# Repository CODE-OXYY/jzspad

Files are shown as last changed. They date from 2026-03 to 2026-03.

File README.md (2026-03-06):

# Custom Multi-Purpose Macropad (jzspad)

A multi-purpose macropad featuring 9 customizable LED-backlit keys, 1 rotary encoder, and an OLED display. Powered by the Seeed Studio XIAO RP2040, The keys change depending on the program, but for now they are copy, paste, undo, mute, cam off, close tab, play / pause, screenshot, and most important- show Desktop :)

## 🛠️ Hardware & PCB Design
## SCHEMATIC

The schematic was designed using KiCad all peripherals (OLED, LEDs, Encoder, Matrix) fit perfectly within the 11 available GPIO pins.

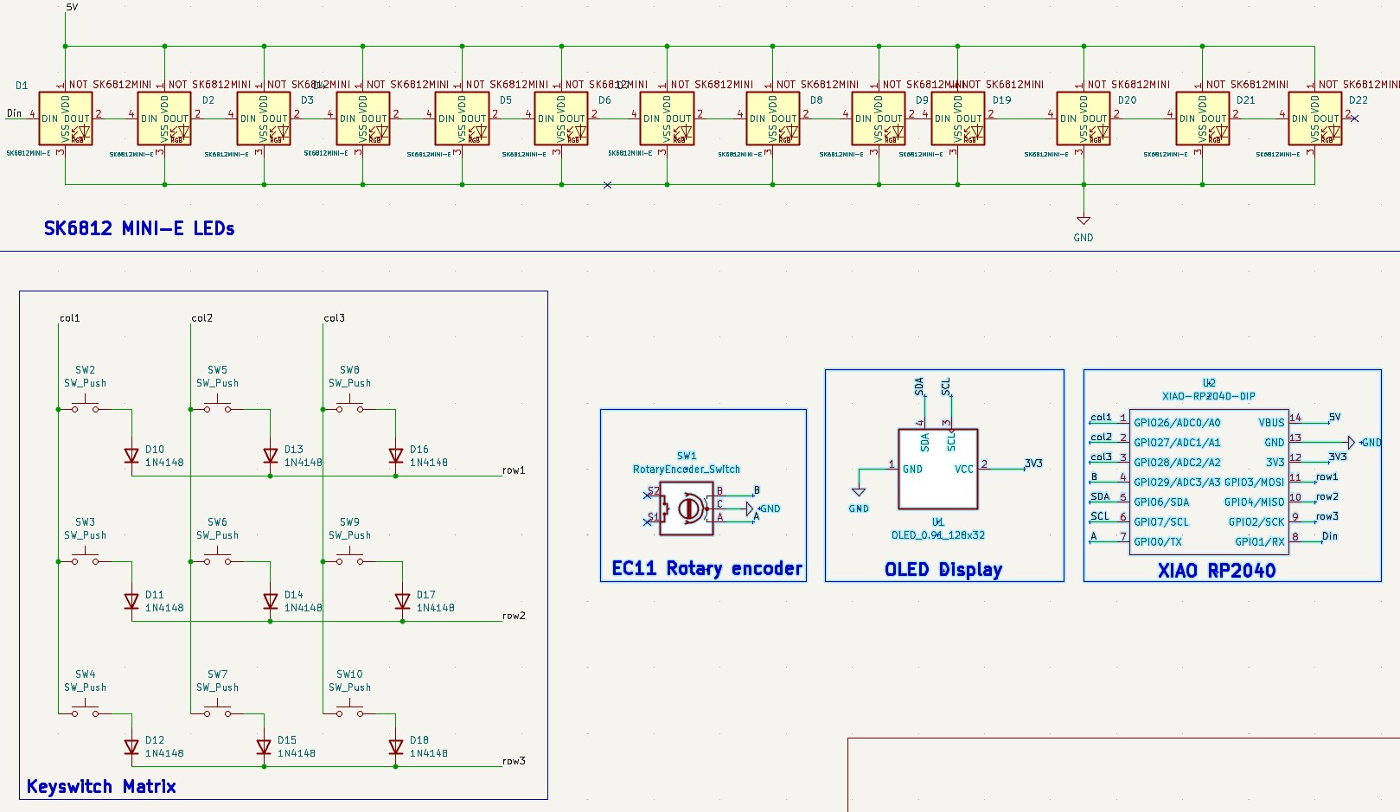
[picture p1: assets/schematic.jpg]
schematic


## PCB LAYOUT

Designed at a precise 98mm x 75mm, staying  Under the 100x100mm threshold.

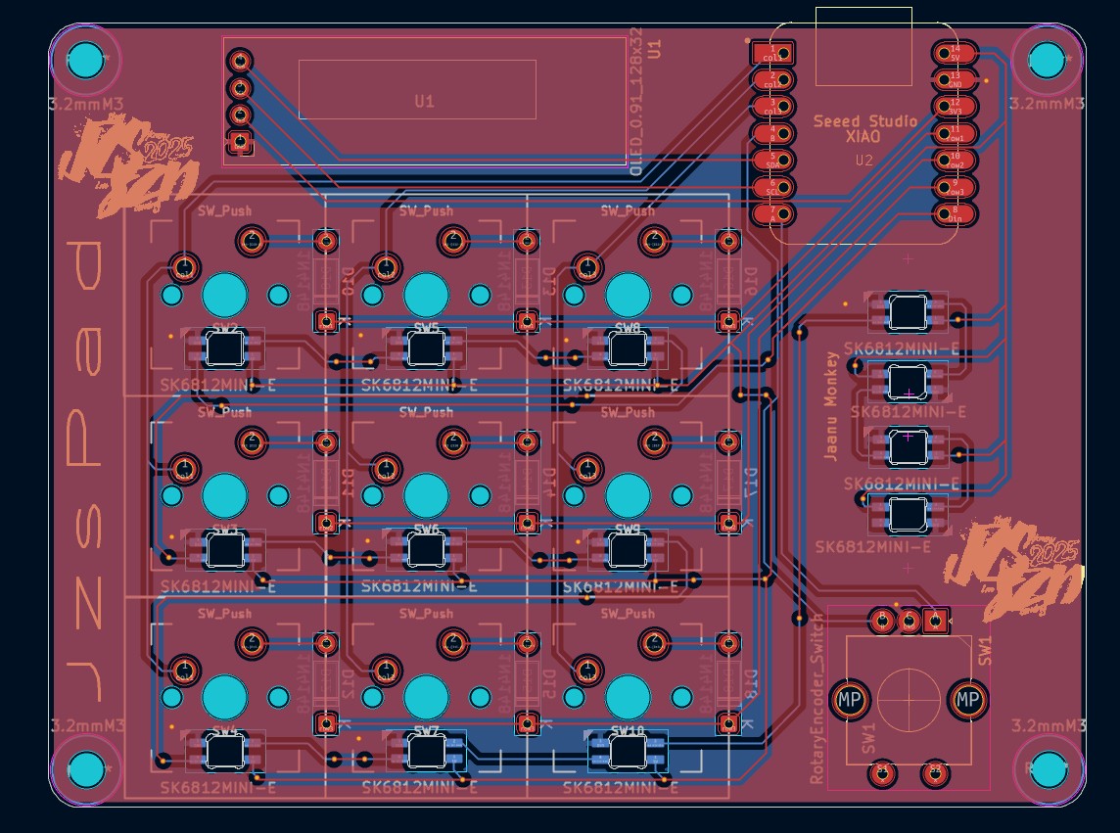
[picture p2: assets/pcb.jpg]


## PCB 3D
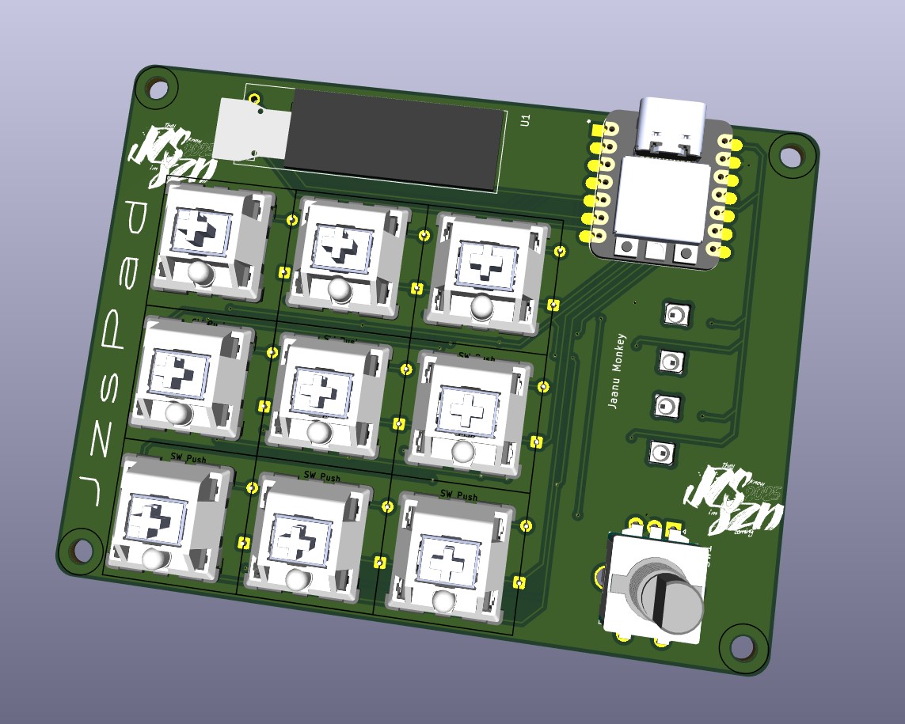
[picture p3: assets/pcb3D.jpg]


## 📦 Mechanical Design (3D Case)
The custom enclosure was modeled in **Onshape**. It features snap-fit or screw-mounted standoffs designed perfectly for the custom PCB layout and keycaps.
## onShape Link- **[View 3D Model on Onshape](https://cad.onshape.com/documents/0e5f4d1caed17afff98262ba/w/1524feb8a85fbf17300e4cda/e/ec6d6c9958024086a6d99712)**

## PLATE MODEL
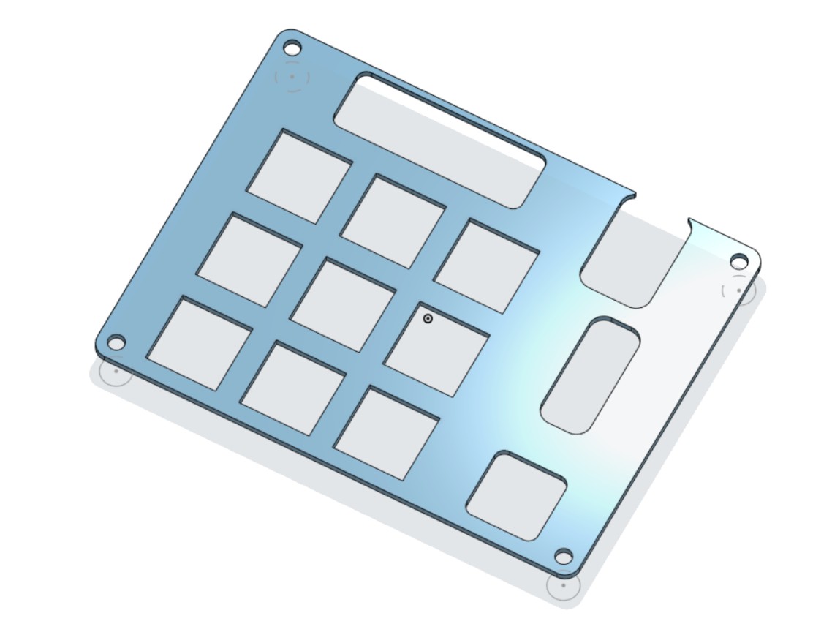
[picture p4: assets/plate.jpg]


## BOTTOM CASE MODEL
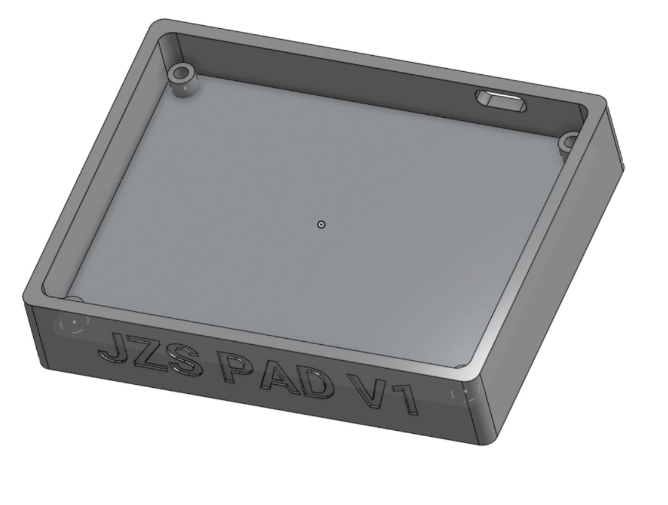
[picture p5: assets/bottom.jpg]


## JZSPAD CAD MODEL

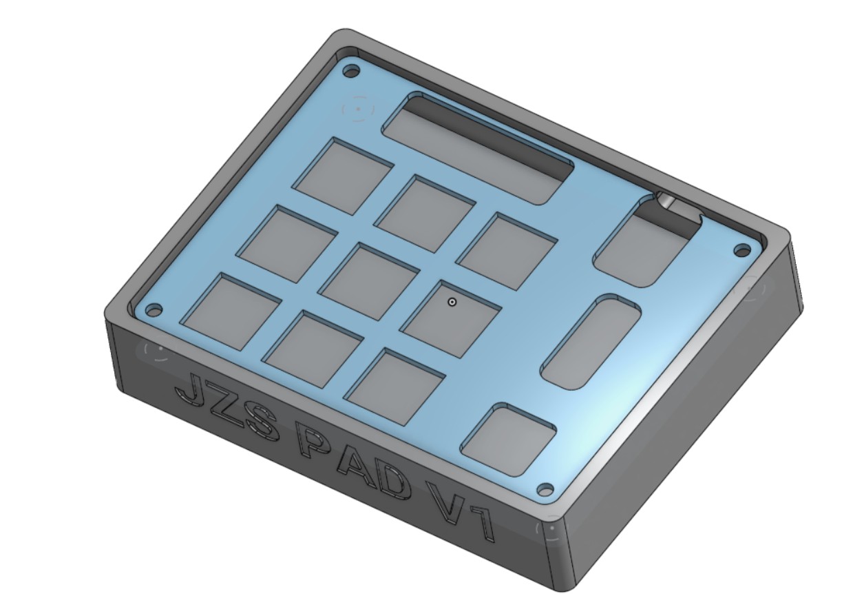
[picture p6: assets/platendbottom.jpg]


## JZS PADCAD & PCB MODEL
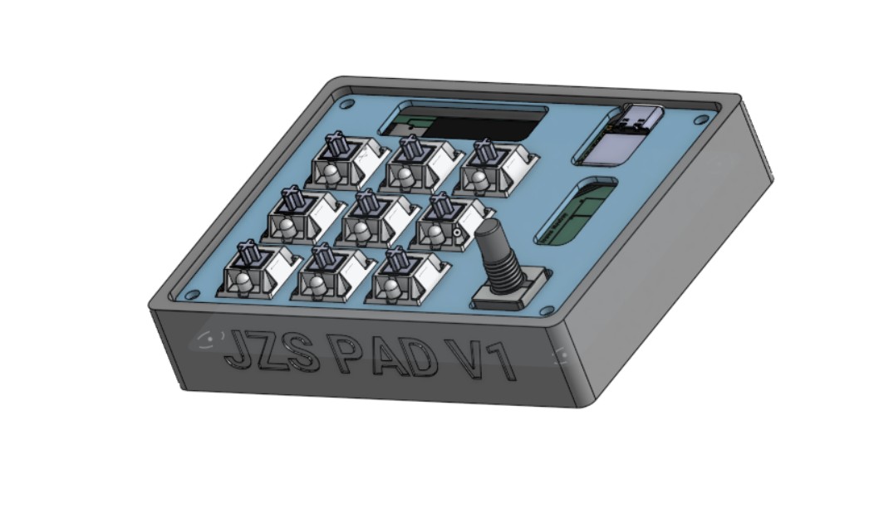
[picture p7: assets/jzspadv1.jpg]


## ✨ Features
* **Microcontroller:** Seeed Studio XIAO RP2040
* **Inputs:** 3x3 Key Matrix (9 Keys) + 1 Rotary Encoder (Volume/Scroll)
* **Visuals:** 128x32 I2C OLED Display for real-time dynamic status updates
* **Lighting:** 13 SK6812MINI-E RGB LEDs 
* **Firmware:** Event-driven KMK framework (CircuitPython)

### 🛒 Bill of Materials (Hardware Needed)
* **9x** MX-Solderable-1U Switches
* **9x** DSA Keycaps
* **4x** M3x5x4 Heatset inserts
* **4x** M3x16mm screws
* **9x** 1N4148 DO-35 Diodes
* **13x** MX_SK6812MINI-E_REV LEDs
* **1x** 0.91" 128x32 OLED Display
* **1x** EC11 Rotary Encoder
* **1x** Seeed Studio XIAO RP2040
* **1x** 3D Printed Case + 1 3D Printed Plate

---

### Extra stuff
**JZS SZN 2025 THEY KNOW IM COMING**

## 📄 License
This project is open-source and available under the **MIT License**.

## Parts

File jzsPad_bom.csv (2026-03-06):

Item Description | Specification / Details | Qty | Reference / Purpose
XIAO RP2040 | Seeed Studio Microcontroller | 1 | U2
0.91" OLED Display | 128x32 Resolution, I2C | 1 | U1
EC11 Rotary Encoder | Standard 20mm with push button | 1 | SW1
MX Mechanical Switches | Solderable, 1U size | 9 | SW2 - SW10
SK6812MINI-E LEDs | RGB, Reverse-Mount | 13 | D1 - D9; D19 - D22
1N4148 Diodes | DO-35 (Through-hole) | 9 | D10 - D18
DSA Profile Keycaps | 1U size, for MX switches | 9 | Key matrix
Heat-set Inserts | M3x5x4mm | 4 | Enclosure mounting
M3 Machine Screws | M3x16mm | 4 | Enclosure assembly
Custom 3D Printed Parts | Switch plate, bottom case | 1 set | Main enclosure

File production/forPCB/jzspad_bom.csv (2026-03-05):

Designator | Footprint | Quantity | Value | LCSC Part #
D1, D19, D2, D20, D21, D22, D3, D4, D5, D6, D7, D8, D9 | MX_SK6812MINI-E_REV (1) | 13 | SK6812MINI-E
D10, D11, D12, D13, D14, D15, D16, D17, D18 | D_DO-35_SOD27_P7.62mm_Horizontal | 9 | 1N4148
SW1 | RotaryEncoder_Alps_EC11E-Switch_Vertical_H20mm_CircularMountingHoles | 1 | RotaryEncoder_Switch
SW10, SW2, SW3, SW4, SW5, SW6, SW7, SW8, SW9 | MX-Solderable-1U | 9 | SW_Push
U1 | OLED_0.91_128x32 | 1 | OLED_0.91_128x32
U2 | XIAO-Generic-Hybrid-14P-2.54-21X17.8MM | 1 | XIAO-RP2040-DIP

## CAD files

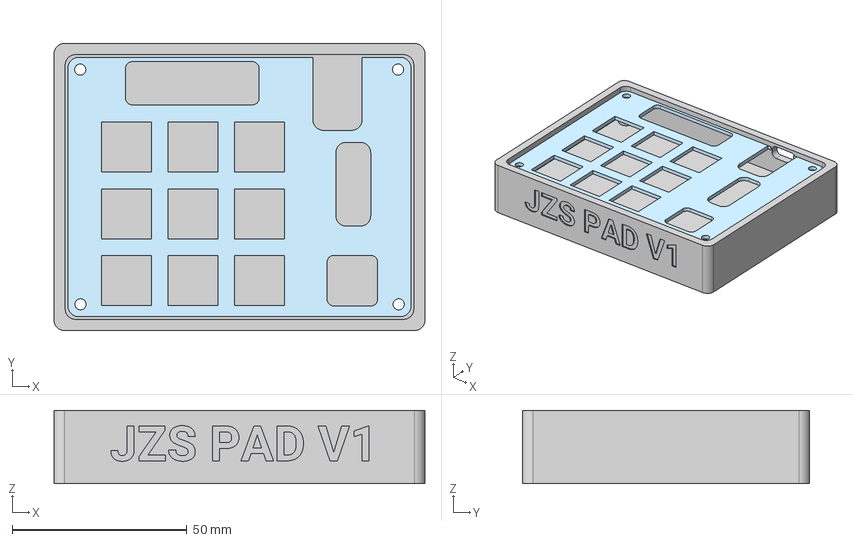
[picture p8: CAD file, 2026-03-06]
cad/jzsCase.step
106.2 x 82.2 x 21.0 mm

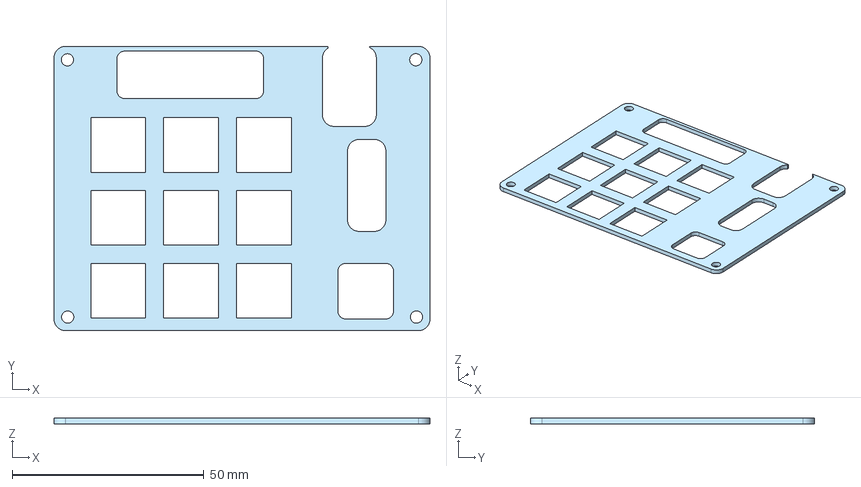
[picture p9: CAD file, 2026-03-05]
cad/plate.step
98.2 x 74.2 x 1.50 mm

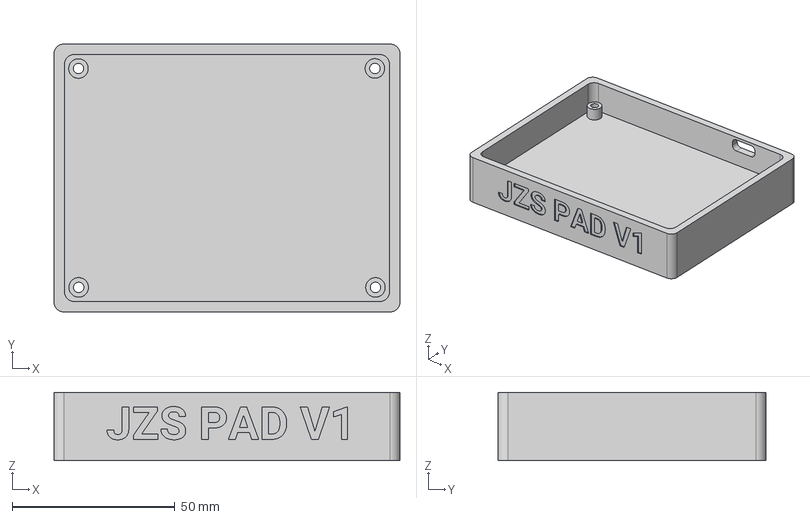
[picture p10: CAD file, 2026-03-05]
cad/bottom.step
106.2 x 82.2 x 21.0 mm

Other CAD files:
production/forCad/plate.step
production/forCad/bottom.step
cad/bottom.stl
cad/jzsCase.stl
cad/plate.stl

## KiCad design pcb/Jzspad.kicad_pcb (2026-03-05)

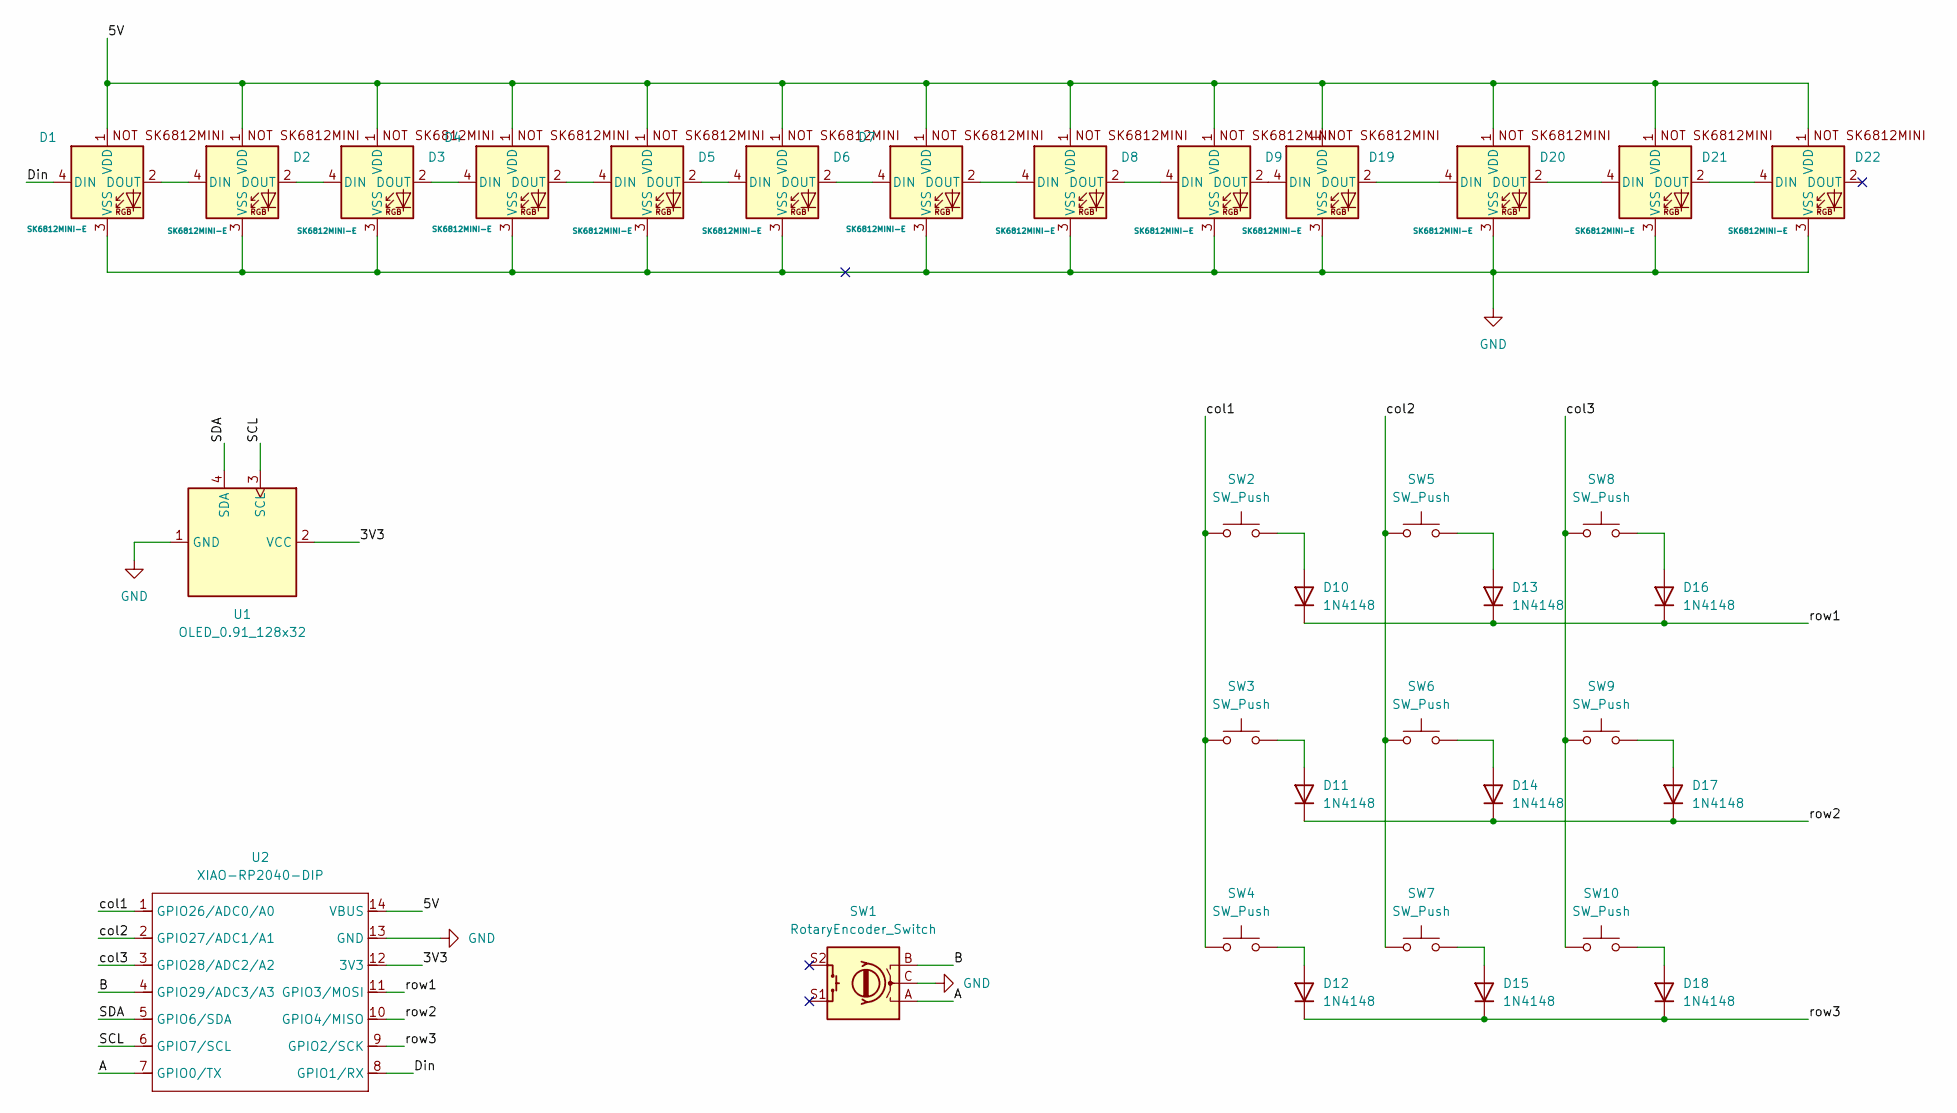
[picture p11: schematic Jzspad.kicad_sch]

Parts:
D1, D2, D3, D4, D5, D6, D7, D8, D9, D19, D20, D21, D22: SK6812MINI-E; MX_SK6812MINI-E_REV (1)
D10, D11, D12, D13, D14, D15, D16, D17, D18: 1N4148; D_DO-35_SOD27_P7.62mm_Horizontal
SW1: RotaryEncoder_Switch; RotaryEncoder_Alps_EC11E-Switch_Vertical_H20mm_CircularMoun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
SW2, SW3, SW4, SW5, SW6, SW7, SW8, SW9, SW10: SW_Push; MX-Solderable-1U
U1: OLED_0.91_128x32
U2: XIAO-RP2040-DIP

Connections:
/3V3: U1.2 (VCC), U2.12 (3V3)
/5V: D1.1 (VDD), D2.1 (VDD), D3.1 (VDD), D4.1 (VDD), D5.1 (VDD), D6.1 (VDD), D7.1 (VDD), D8.1 (VDD), D9.1 (VDD), D19.1 (VDD), D20.1 (VDD), D21.1 (VDD), D22.1 (VDD), U2.14 (VBUS)
/A: SW1.A, U2.7 (GPIO0/TX)
/B: SW1.B, U2.4 (GPIO29/ADC3/A3)
/Din: D1.4 (DIN), U2.8 (GPIO1/RX)
/SCL: U1.3 (SCL), U2.6 (GPIO7/SCL)
/SDA: U1.4 (SDA), U2.5 (GPIO6/SDA)
/col1: SW2.1, SW3.1, SW4.1, U2.1 (GPIO26/ADC0/A0)
/col2: SW5.1, SW6.1, SW7.1, U2.2 (GPIO27/ADC1/A1)
/col3: SW8.1, SW9.1, SW10.1, U2.3 (GPIO28/ADC2/A2)
/row1: D10.1 (K), D13.1 (K), D16.1 (K), U2.11 (GPIO3/MOSI)
/row2: D11.1 (K), D14.1 (K), D17.1 (K), U2.10 (GPIO4/MISO)
/row3: D12.1 (K), D15.1 (K), D18.1 (K), U2.9 (GPIO2/SCK)
GND: D1.3 (VSS), D2.3 (VSS), D3.3 (VSS), D4.3 (VSS), D5.3 (VSS), D6.3 (VSS), D7.3 (VSS), D8.3 (VSS), D9.3 (VSS), D19.3 (VSS), D20.3 (VSS), D21.3 (VSS), D22.3 (VSS), SW1.C, U1.1 (GND), U2.13 (GND)
unnamed: D1.2 (DOUT), D2.4 (DIN)
unnamed: D2.2 (DOUT), D3.4 (DIN)
unnamed: D3.2 (DOUT), D4.4 (DIN)
unnamed: D4.2 (DOUT), D5.4 (DIN)
unnamed: D5.2 (DOUT), D6.4 (DIN)
unnamed: D6.2 (DOUT), D7.4 (DIN)
unnamed: D7.2 (DOUT), D8.4 (DIN)
unnamed: D8.2 (DOUT), D9.4 (DIN)
unnamed: D10.2 (A), SW2.2
unnamed: D11.2 (A), SW3.2
unnamed: D12.2 (A), SW4.2
unnamed: D13.2 (A), SW5.2
unnamed: D14.2 (A), SW6.2
unnamed: D15.2 (A), SW7.2
unnamed: D16.2 (A), SW8.2
unnamed: D17.2 (A), SW9.2
unnamed: D18.2 (A), SW10.2
unnamed: D9.2 (DOUT), D19.4 (DIN)
unnamed: D19.2 (DOUT), D20.4 (DIN)
unnamed: D20.2 (DOUT), D21.4 (DIN)
unnamed: D21.2 (DOUT), D22.4 (DIN)

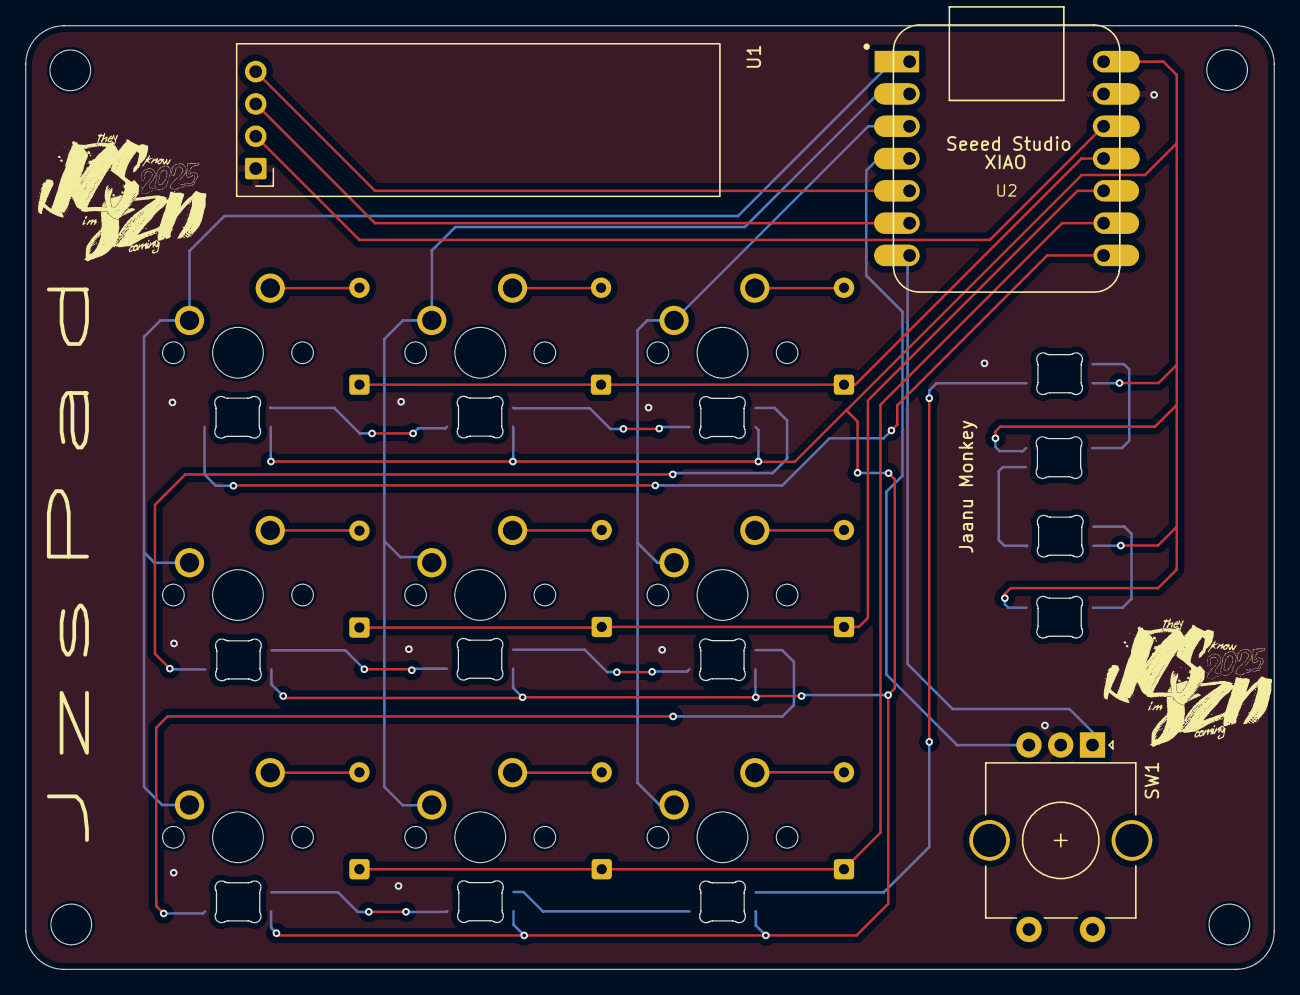
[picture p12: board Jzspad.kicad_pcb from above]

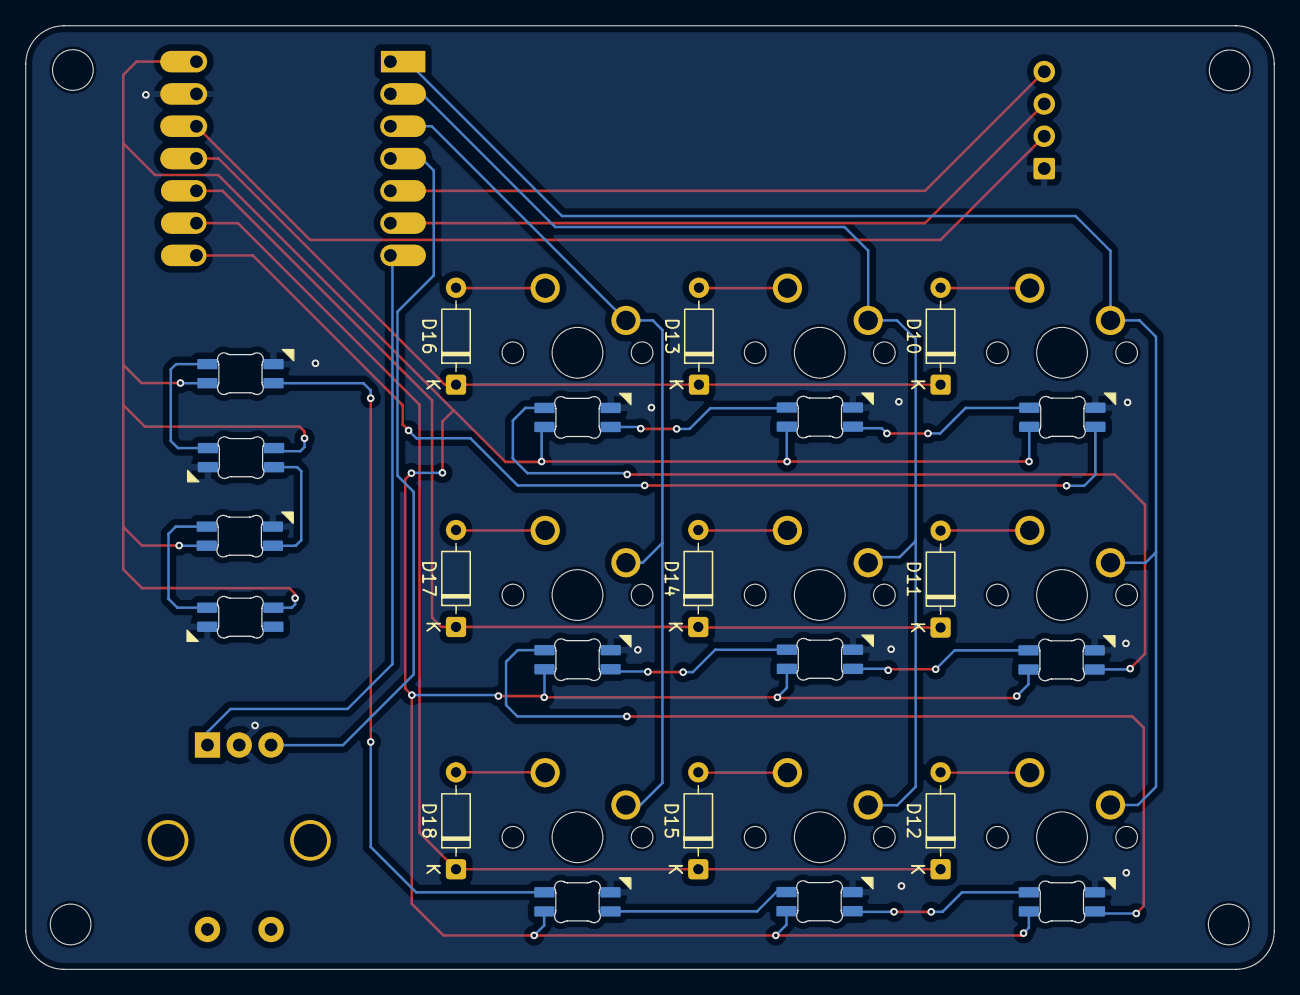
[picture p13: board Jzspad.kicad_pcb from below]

Board: 2 copper layers, 98.2 x 74.2 mm, 34 parts (9 on the bottom side), 35 nets.

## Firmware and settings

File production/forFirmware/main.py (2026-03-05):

import board
import busio
import time
import displayio
import terminalio
from adafruit_display_text import label
from kmk.kmk_keyboard import KMKKeyboard
from kmk.keys import KC
from kmk.scanners import DiodeOrientation
from kmk.modules.encoder import EncoderHandler
from kmk.modules.rgb import RGB
from kmk.modules import Module
import adafruit_displayio_ssd1306 

keyboard = KMKKeyboard()

# keySwitch Matrix

keyboard.col_pins = (board.D0, board.D1, board.D2) 
keyboard.row_pins = (board.D10, board.D9, board.D8) 
keyboard.diode_orientation = DiodeOrientation.COL2ROW

# other components

encoder_handler = EncoderHandler()
encoder_handler.pins = ((board.D6, board.D3, None, False),) 
keyboard.modules.append(encoder_handler)
rgb = RGB(pixel_pin=board.D7, num_pixels=13, val=127) 
keyboard.modules.append(rgb)

# oled display
displayio.release_displays()
i2c = busio.I2C(board.D5, board.D4)
display_bus = displayio.I2CDisplay(i2c, device_address=0x3C)
display = adafruit_displayio_ssd1306.SSD1306(display_bus, width=128, height=32)
splash = displayio.Group()
display.show(splash)
status_label = label.Label(terminalio.FONT, text="READY", color=0xFFFFFF, x=10, y=16)
splash.append(status_label)



# keySwitch and encoder maping

keyboard.keymap = [
    [
        KC.F9,                  KC.F10,                 KC.MPLY,
        KC.LCTRL(KC.Z),         KC.LCTRL(KC.C),         KC.LCTRL(KC.V),
        KC.LGUI(KC.LSFT(KC.S)), KC.LCTRL(KC.W),         KC.LGUI(KC.D)
    ]
]
encoder_handler.map = [ ((KC.VOLD, KC.VOLU, None),) ]

# ui state logic
class UIHook(Module):
    def __init__(self):
        self.last_anim_time = time.monotonic()
        self.anim_frame = 0
        self.showing_temp_msg = False
        self.msg_timeout = 0
        self.vol = 10

    def during_bootup(self, keyboard): pass
    def after_matrix_scan(self, keyboard): pass
    def before_hid_send(self, keyboard): pass
    def after_hid_send(self, keyboard): pass

    def before_matrix_scan(self, keyboard):
        curr_time = time.monotonic()
        if not self.showing_temp_msg:
            if curr_time - self.last_anim_time > 0.5:
                frames = ["IDLE .", "IDLE ..", "IDLE ..."]
                status_label.text = frames[self.anim_frame]
                self.anim_frame = (self.anim_frame + 1) % 3
                self.last_anim_time = curr_time
        elif curr_time > self.msg_timeout:
            self.showing_temp_msg = False

    def process_key(self, keyboard, key, is_pressed, int_coord):
        if is_pressed:
            self.showing_temp_msg = True
            self.msg_timeout = time.monotonic() + 1.5
            
            if key == KC.VOLU:
                self.vol = min(20, self.vol + 1)
                bar = "|" * (self.vol // 2)
                status_label.text = f"VOL: [{bar.ljust(10, ' ')}]"
            elif key == KC.VOLD:
                self.vol = max(0, self.vol - 1)
                bar = "|" * (self.vol // 2)
                status_label.text = f"VOL: [{bar.ljust(10, ' ')}]"
            elif key == KC.F9:
                status_label.text = "MIC MUTED"
            elif key == KC.F10:
                status_label.text = "CAM OFF"
            elif key == KC.LCTRL(KC.W):
                status_label.text = "TAB CLOSED"
            else:
                status_label.text = "SENT"
        return key

keyboard.modules.append(UIHook())

if __name__ == '__main__':
    keyboard.go()

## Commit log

2026-03-06 added whole case step file
    [bottom.step, jzsCase.step, plate.step]
2026-03-06 updated stl files
    [bottom.stl, jzsCase.stl, plate.stl]
2026-03-06 added bom
    [jzsPad_bom.csv]
2026-03-06 added step files
    [Plate.step, bottomcase.step, jzsCase.step]
